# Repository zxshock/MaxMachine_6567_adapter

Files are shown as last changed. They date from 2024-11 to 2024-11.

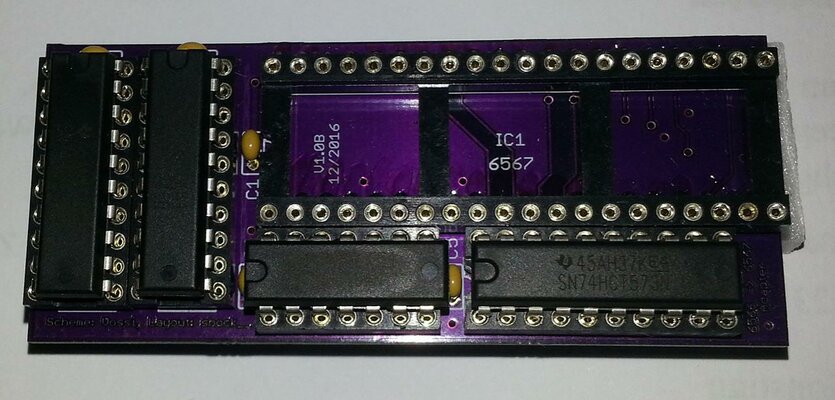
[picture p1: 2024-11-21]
prev1.jpg

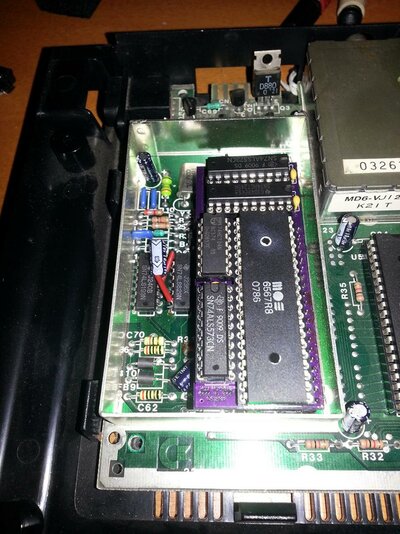
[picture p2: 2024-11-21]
prev2.jpg

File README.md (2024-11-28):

Original development by vossi: http://lc64.blogspot.com/2016/08/max6566-replacement-pcb-finshed.html
Prototyped in 2016

Documentation is "okayish". Uploaded completely "as is", since I lost all interest in the Commodore community.
Uploaded for your personal enjoyment. If I see this advertised as "r@r3 l@@k - high quality Repro of a long lost expansion!!!!!!11one" for 50€+ on eBay I sincerely hope you're getting the customers you deserve :)
The same circuit/blank PCB is also available with a different layout for a fair price at "Retro Innovations" / "go4retro"

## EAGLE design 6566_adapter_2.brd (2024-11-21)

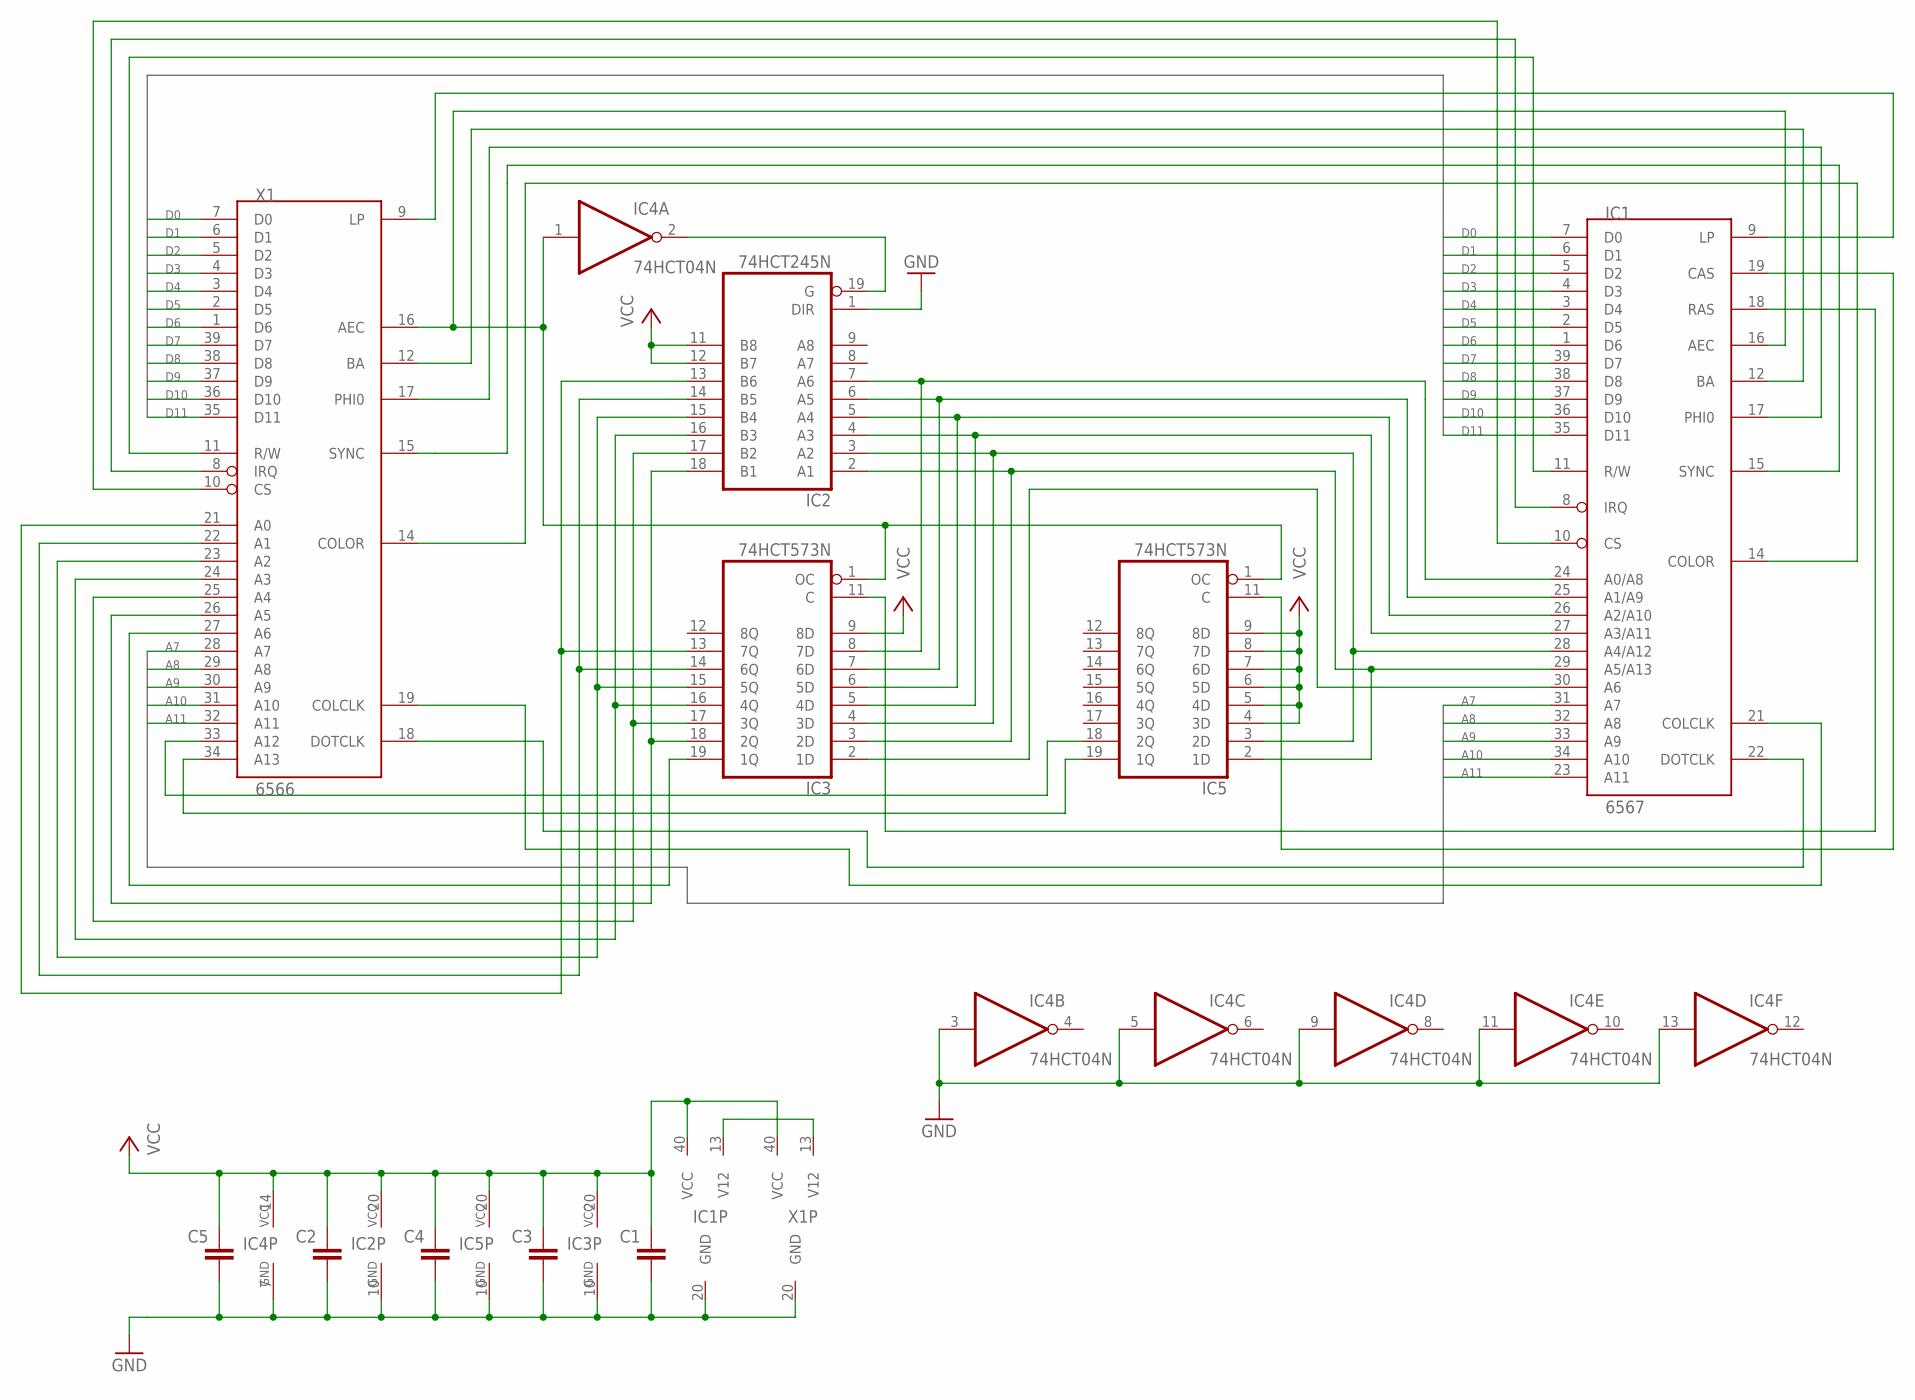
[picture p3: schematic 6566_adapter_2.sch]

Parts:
C1, C2, C3, C4, C5: C-EU025-025X050; C025-025X050
IC1: 6567; DIP40
IC2: 74HCT245N; DIL20
IC3, IC5: 74HCT573N; DIL20
IC4: 74HCT04N; DIL14
X1: 6566; DIL40

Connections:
!AEC: IC2.19 (G), IC4.2 (O)
!CS: IC1.10 (CS), X1.10 (CS)
!IRQ: IC1.8 (IRQ), X1.8 (IRQ)
A0: IC2.13 (B6), IC3.13 (7Q), X1.21 (A0)
A0_6567: IC1.24 (A0/A8), IC2.7 (A6), IC3.8 (7D)
A1: IC2.14 (B5), IC3.14 (6Q), X1.22 (A1)
A1_6567: IC1.25 (A1/A9), IC2.6 (A5), IC3.7 (6D)
A2: IC2.15 (B4), IC3.15 (5Q), X1.23 (A2)
A2_6567: IC1.26 (A2/A10), IC2.5 (A4), IC3.6 (5D)
A3: IC2.16 (B3), IC3.16 (4Q), X1.24 (A3)
A3_6567: IC1.27 (A3/A11), IC2.4 (A3), IC3.5 (4D)
A4: IC2.17 (B2), IC3.17 (3Q), X1.25 (A4)
A4_6567: IC1.28 (A4/A12), IC2.3 (A2), IC3.4 (3D), IC5.3 (2D)
A5: IC2.18 (B1), IC3.18 (2Q), X1.26 (A5)
A5_6567: IC1.29 (A5/A13), IC2.2 (A1), IC3.3 (2D), IC5.2 (1D)
A6: IC3.19 (1Q), X1.27 (A6)
A6_6567: IC1.30 (A6), IC3.2 (1D)
A7: IC1.31 (A7), X1.28 (A7)
A8: IC1.32 (A8), X1.29 (A8)
A9: IC1.33 (A9), X1.30 (A9)
A10: IC1.34 (A10), X1.31 (A10)
A11: IC1.23 (A11), X1.32 (A11)
A12: IC5.18 (2Q), X1.33 (A12)
A13: IC5.19 (1Q), X1.34 (A13)
AEC: IC1.16 (AEC), IC3.1 (OC), IC4.1 (I), IC5.1 (OC), X1.16 (AEC)
BA: IC1.12 (BA), X1.12 (BA)
CAS: IC1.19 (CAS), IC5.11 (C)
COLCLK: IC1.21 (COLCLK), X1.19 (COLCLK)
COLOR: IC1.14 (COLOR), X1.14 (COLOR)
D0: IC1.7 (D0), X1.7 (D0)
D1: IC1.6 (D1), X1.6 (D1)
D2: IC1.5 (D2), X1.5 (D2)
D3: IC1.4 (D3), X1.4 (D3)
D4: IC1.3 (D4), X1.3 (D4)
D5: IC1.2 (D5), X1.2 (D5)
D6: IC1.1 (D6), X1.1 (D6)
D7: IC1.39 (D7), X1.39 (D7)
D8: IC1.38 (D8), X1.38 (D8)
D9: IC1.37 (D9), X1.37 (D9)
D10: IC1.36 (D10), X1.36 (D10)
D11: IC1.35 (D11), X1.35 (D11)
DOTCLK: IC1.22 (DOTCLK), X1.18 (DOTCLK)
GND: C1.2, C2.2, C3.2, C4.2, C5.2, IC1.20 (GND), IC2.1 (DIR), IC2.10 (GND), IC3.10 (GND), IC4.3 (I), IC4.5 (I), IC4.7 (GND), IC4.9 (I), IC4.11 (I), IC4.13 (I), IC5.10 (GND), X1.20 (GND)
LP: IC1.9 (LP), X1.9 (LP)
PHI0: IC1.17 (PHI0), X1.17 (PHI0)
R/W: IC1.11 (R/W), X1.11 (R/W)
RAS: IC1.18 (RAS), IC3.11 (C)
SYNC: IC1.15 (SYNC), X1.15 (SYNC)
V12: IC1.13 (V12), X1.13 (V12)
VCC: C1.1, C2.1, C3.1, C4.1, C5.1, IC1.40 (VCC), IC2.11 (B8), IC2.12 (B7), IC2.20 (VCC), IC3.9 (8D), IC3.20 (VCC), IC4.14 (VCC), IC5.4 (3D), IC5.5 (4D), IC5.6 (5D), IC5.7 (6D), IC5.8 (7D), IC5.9 (8D), IC5.20 (VCC), X1.40 (VCC)

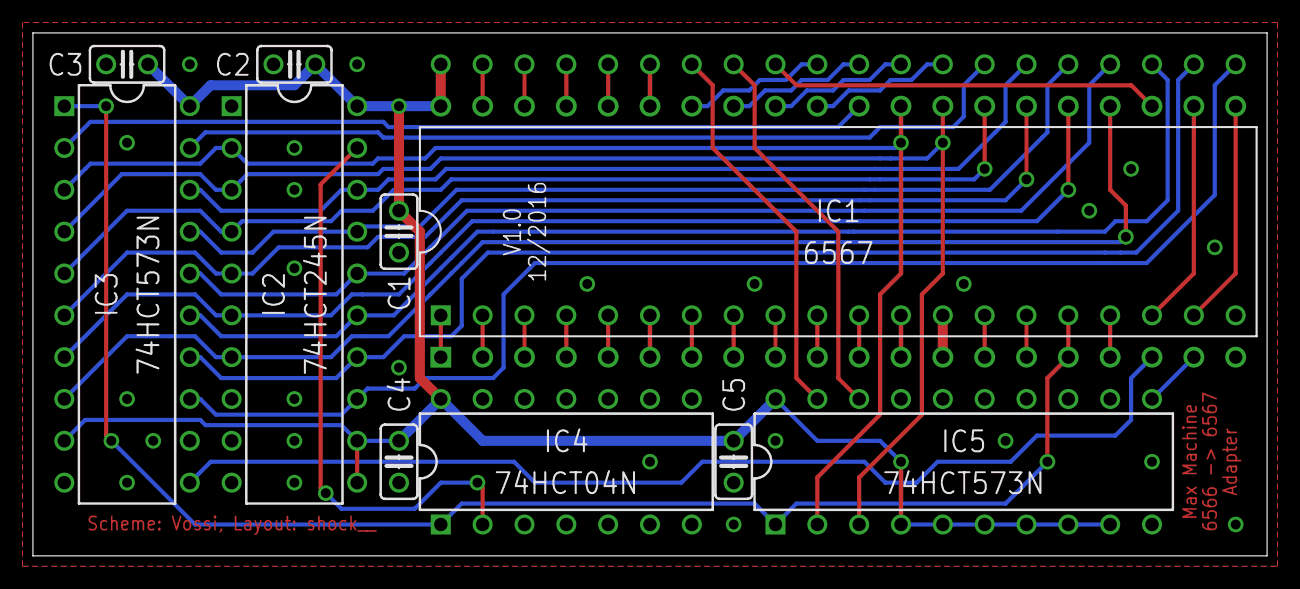
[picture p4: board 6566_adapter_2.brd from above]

Board: 2 copper layers, 74.9 x 31.8 mm, 11 parts (0 on the bottom side), 50 nets.
